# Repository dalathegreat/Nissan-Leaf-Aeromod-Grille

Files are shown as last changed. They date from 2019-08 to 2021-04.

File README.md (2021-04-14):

# Nissan-Leaf-Aeromod-Grille
A 3d printable aeromod for your first gen Nissan Leaf (2011-2017)

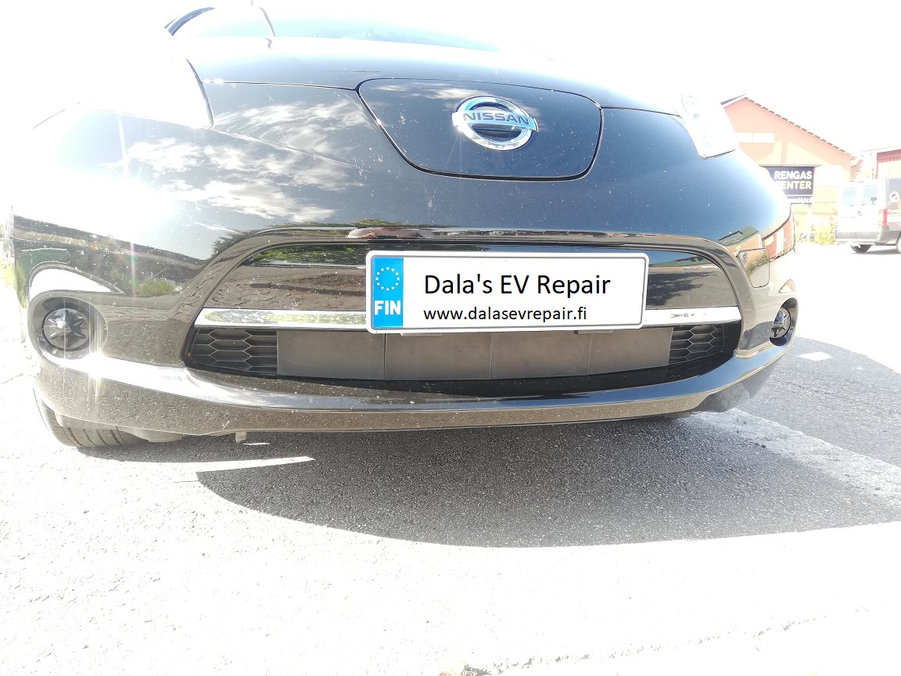
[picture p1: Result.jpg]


Gone are the days of using tape to achieve an aero grille block!

Reduce the aero drag of your Nissan Leaf with this modular grille blocker! Lowers consumption, makes you go further on a single charge!

Confirmed working with 2013-2017 AZE0, should also work on 2011-2012 ZE0, please report back!

Printer notes:
Tested with both PLA and PETG. Should also work well with ABS. Split into 4 sections, you need a printer capable of 18cm width

The hooks are extremely important, so use slow speed or really hot temp with PETG, there is a tradeoff with stringing/layer adhesion, but always prioritize adhesion on this component.

Always print in black for a stealthy look ;)

How to install after printing, sections are numbered
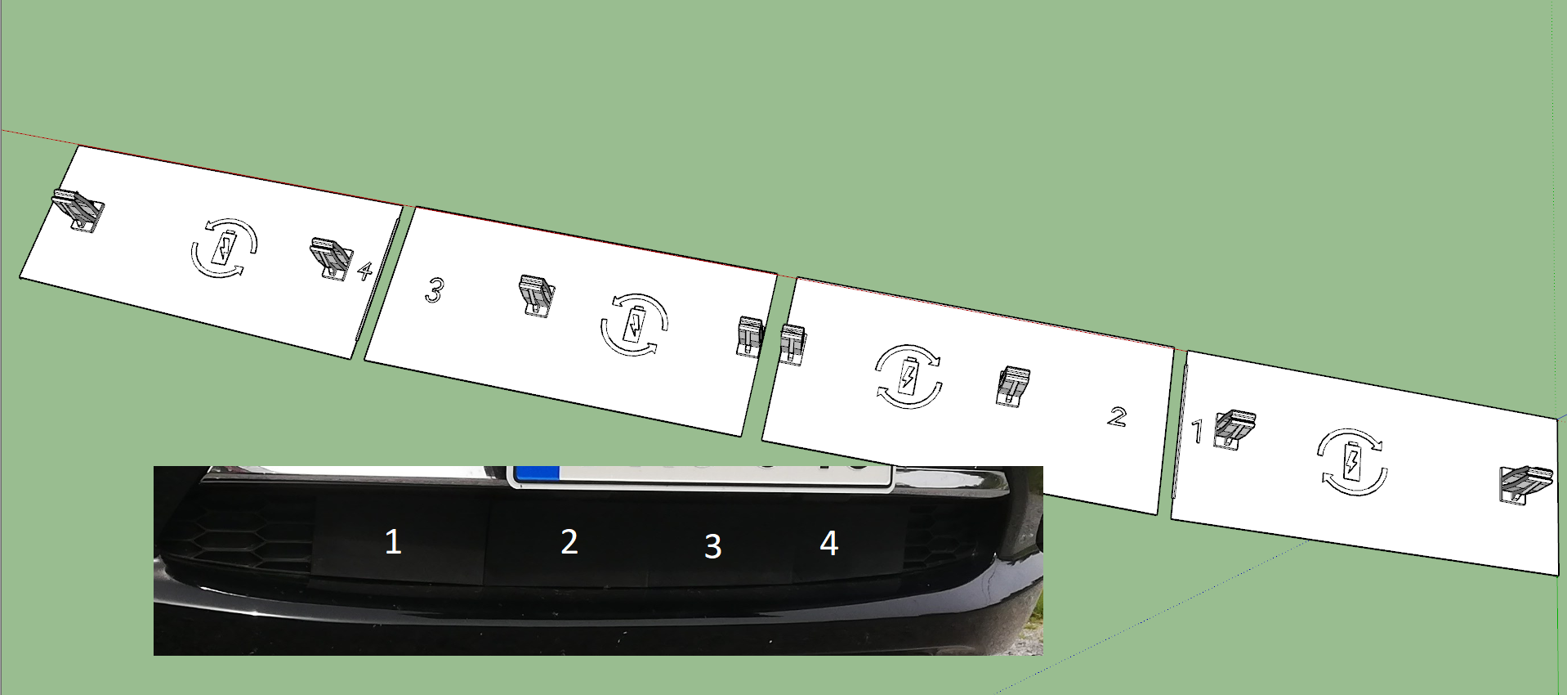
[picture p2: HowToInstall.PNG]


Update version 2:

-Fixed faulty hooks

-All logos and numbers on the back now raised fråm the plate for better printing results

Design by Dala's EV Repair
www.dalasevrepair.fi

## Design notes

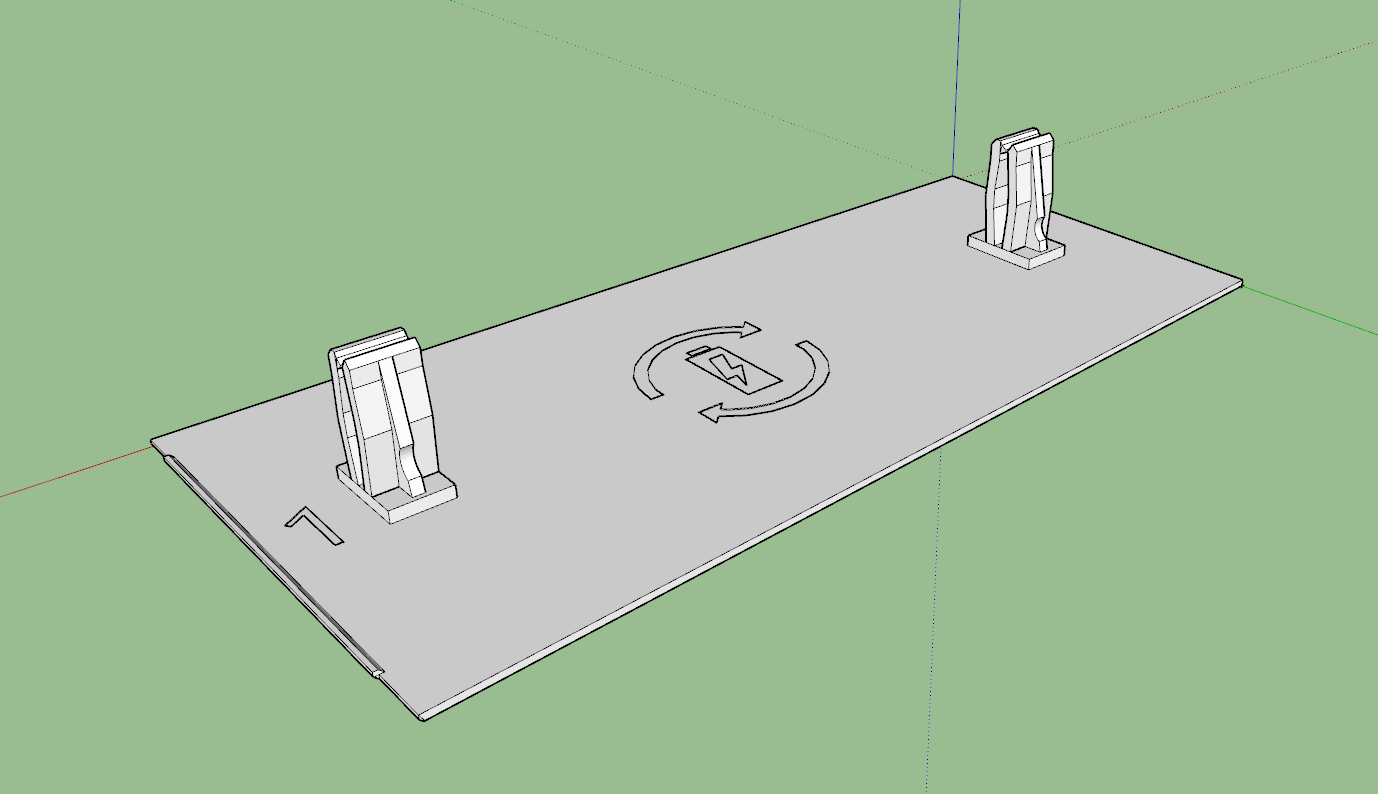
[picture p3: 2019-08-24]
Sketchup.PNG

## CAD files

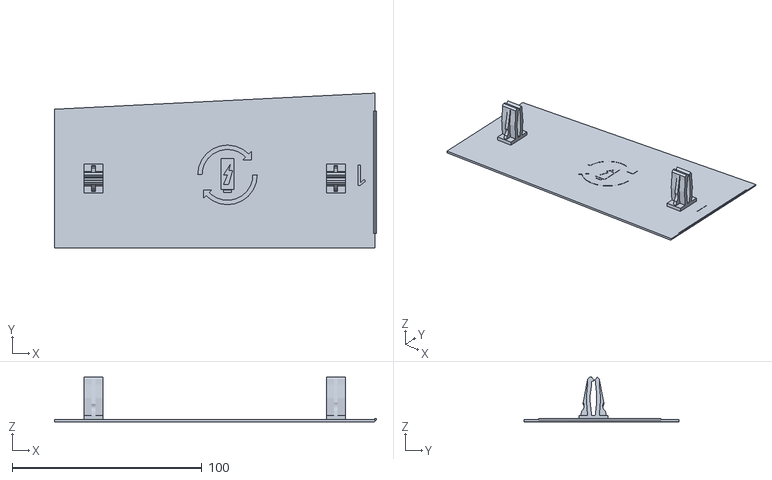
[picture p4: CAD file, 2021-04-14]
1of4_AeroLeafIntakeBlockerVersion2.stl
169.5 x 81.5 x 23.7

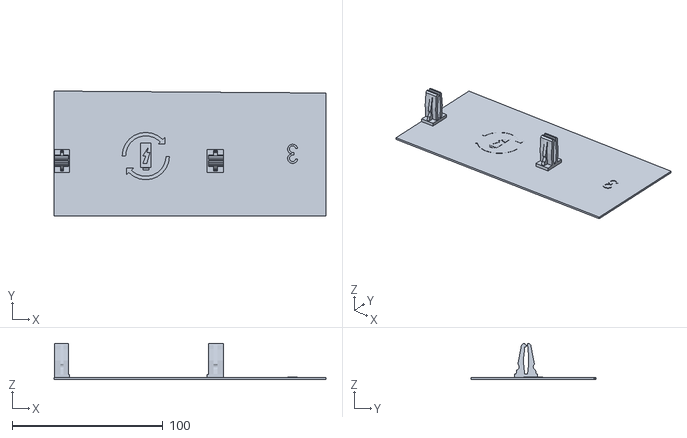
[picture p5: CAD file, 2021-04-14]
3of4_AeroLeafIntakeBlockerVersion2.stl
180.3 x 82.8 x 23.9

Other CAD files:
2of4_AeroLeafIntakeBlockerVersion2.stl
4of4_AeroLeafIntakeBlockerVersion2.stl

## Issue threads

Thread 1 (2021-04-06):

Flaw in the STL file for 2nd and 3rd parts

alozzy, 2021-04-06:
Hi Daniel,

Just a heads up that there appears to be a flaw in the model for 2of4_AeroLeafIntakeBlockerVersion1.stl and 3of4_AeroLeafIntakeBlockerVersion1.stl

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

I've circled in red the part of the retaining clip where it appears the model is missing material

dalathegreat, 2021-04-06:
ping @Johan-92 , could you fix it? :)

Johan-92, 2021-04-11:
>
>
> ping @Johan-92 , could you fix it? :)

Will do ASAP

dalathegreat, 2021-04-14:
Massive thanks to Johan for fixing this in https://github.com/dalathegreat/Nissan-Leaf-Aeromod-Grille/pull/2

Closed 2021-04-14.

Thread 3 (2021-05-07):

Material type imprint

Erasmo12321, 2021-05-07:
Maybe an idea for the next generation, it would be nice to also have a little raised text on the back with the material code for future recycling clarity .

Erasmo12321, 2021-05-10:
Of course depends on what the user wants to print with. I don't have access to modeling software at the moment but I'll see if I can add it later for the most common materials. Shouldn't be more than adding text on the back and raising it a mm.

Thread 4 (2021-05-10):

Fitment on ZE0

Erasmo12321, 2021-05-10:
Just did a test fit on a ZE0, seems to fit well. Will report back in some time for longer term fitment.

Erasmo12321, 2021-05-10:
Indeed but with the summer temperatures that might be more of an advantage then an issue. Since the grill is flat it shouldn't be that hard to extend fully. I can do some measurements later for the sides if you want.

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

dalathegreat, 2021-05-11:
I actually have access to a ZE0 LEAF, so no need to take measurements! I just haven't gotten around to fixing these :)

Erasmo12321, 2021-05-12:
Neat. So far no issues, didn't do a lot of testing but it seem have a noticeable difference on the motorway.

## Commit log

2019-08-24 First release of the Aero grille
    Added all project files
    [1of4_AeroLeafIntakeBlockerVersion1.stl, 2of4_AeroLeafIntakeBlockerVersion1.stl, 3of4_AeroLeafIntakeBlockerVersion1.stl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]
2019-08-24 Updated readme with info how to print
2021-04-12 Delete 4of4_AeroLeafIntakeBlockerVersion1.stl
    Removal of old version
    [4of4_AeroLeafIntakeBlockerVersion1.stl]
2021-04-12 Delete 3of4_AeroLeafIntakeBlockerVersion1.stl
    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
    [3of4_AeroLeafIntakeBlockerVersion1.stl]
2021-04-12 Delete 2of4_AeroLeafIntakeBlockerVersion1.stl
    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
    [2of4_AeroLeafIntakeBlockerVersion1.stl]
2021-04-12 Update readme
    STL files replaced with version 2
